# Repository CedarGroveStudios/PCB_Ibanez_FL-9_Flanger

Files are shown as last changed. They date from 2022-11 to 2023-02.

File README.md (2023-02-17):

## PCB_Ibanez_FL-9_Flanger
 An as-built schematic, PCB layout, and service guide to help with the repair of the Ibanez FL-9 Flanger guitar pedal.
 
 [FL9 Flanger Repair Blog (.pdf)](https://github.com/CedarGroveStudios/PCB_Ibanez_FL-9_Flanger/blob/main/docs/repair_blog/Ibanez_FL9_Flanger_Repair_Blog.pdf)

 [New Service Guide (Adafruit Learning System)](https://learn.adafruit.com/u/CGrover/pages/ibanez-fl9-service-guide)

 [New Service Guide (.pdf)](https://github.com/CedarGroveStudios/PCB_Ibanez_FL-9_Flanger/blob/main/docs/new_service_guide/Ibanez_FL9_Service_Guide.pdf)
 
 [KiCAD PCB Design Folder](https://github.com/CedarGroveStudios/PCB_Ibanez_FL-9_Flanger/tree/main/PCB)

 NOTE: The reverse-engineered PCB design was only used for relative component location -- the design is untested.

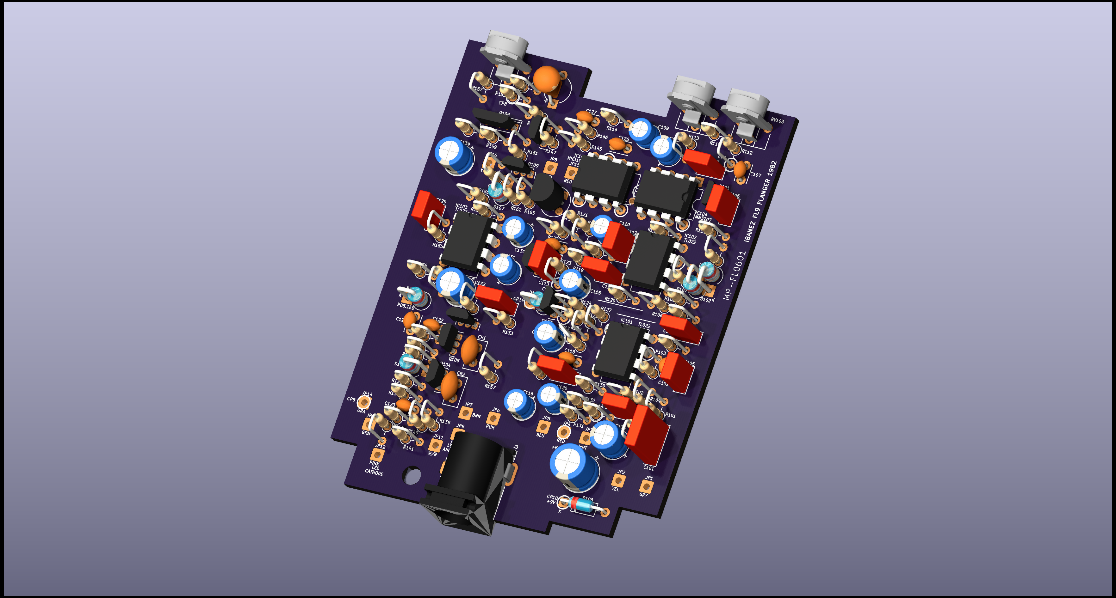
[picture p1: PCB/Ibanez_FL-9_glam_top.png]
PCB 3D rendered view


A thank you to [Mystic Effects Co](https://mysticeffectsco.com) for a helpful and inspiring FL9 capacitor replacement blog post. Also to Panasonic for continuing to maintain on-line datasheets for the bucket-brigade delay and clock driver chip set. Let's not forget how great it is that DigiKey still stocks fresh through-hole capacitors in their produce aisle.

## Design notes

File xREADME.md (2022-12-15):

# PCB_Ibanez_FL-9_Flanger
 An as-built schematic, PCB, and service guide to help with the repair of the Ibanez FL-9 Flanger guitar pedal.
 
 [New Service Guide](https://github.com/CedarGroveStudios/PCB_Ibanez_FL-9_Flanger/blob/main/docs/new_service_guide/Ibanez_FL9_Service_Guide.pdf)
 
 NOTE: At this time, the reverse-engineered PCB design is only useful for relative component location -- the design is non-functional and cannot be fabricated as-is. However, the process to convert a photograph of the traces into a copper layer was tested during this re-engineering project. Further work needs to be done to process the photograph to eliminate shadow and reflective anomolies before a practical test can be conducted. That's on the to-do list.

PCB 3D rendered view

A thank you to [Mystic Effects Co](https://mysticeffectsco.com) for a helpful and inspiring FL9 capacitor replacement blog post. Also to Panasonic for continuing to maintain on-line datasheets for the bucket brigade delay and clock driver chip set. Let's not forget how great it is that @DigiKey still stocks fresh through-hole capacitors in their produce aisle.

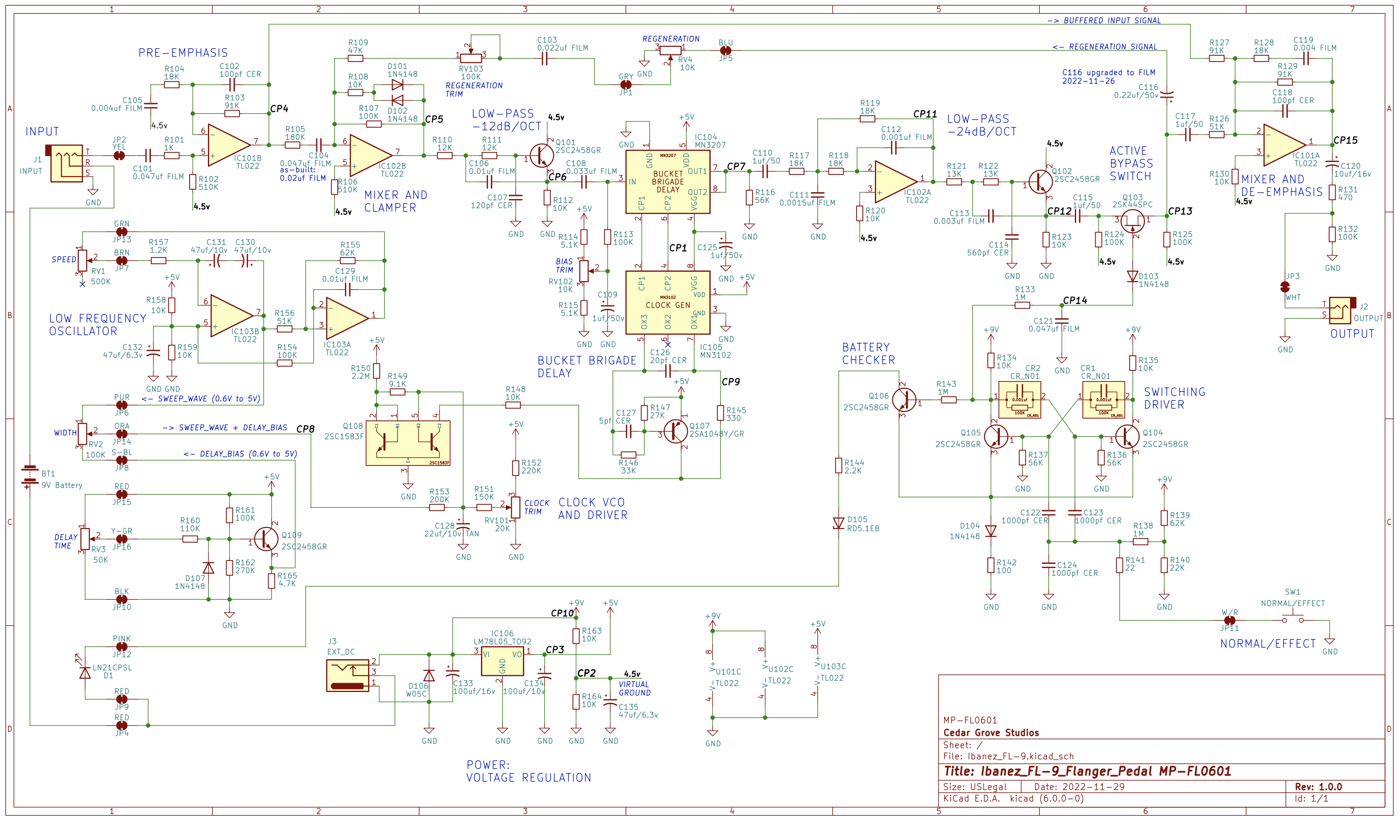
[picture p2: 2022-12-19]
media/guide_photos_and_graphics/schematic.png

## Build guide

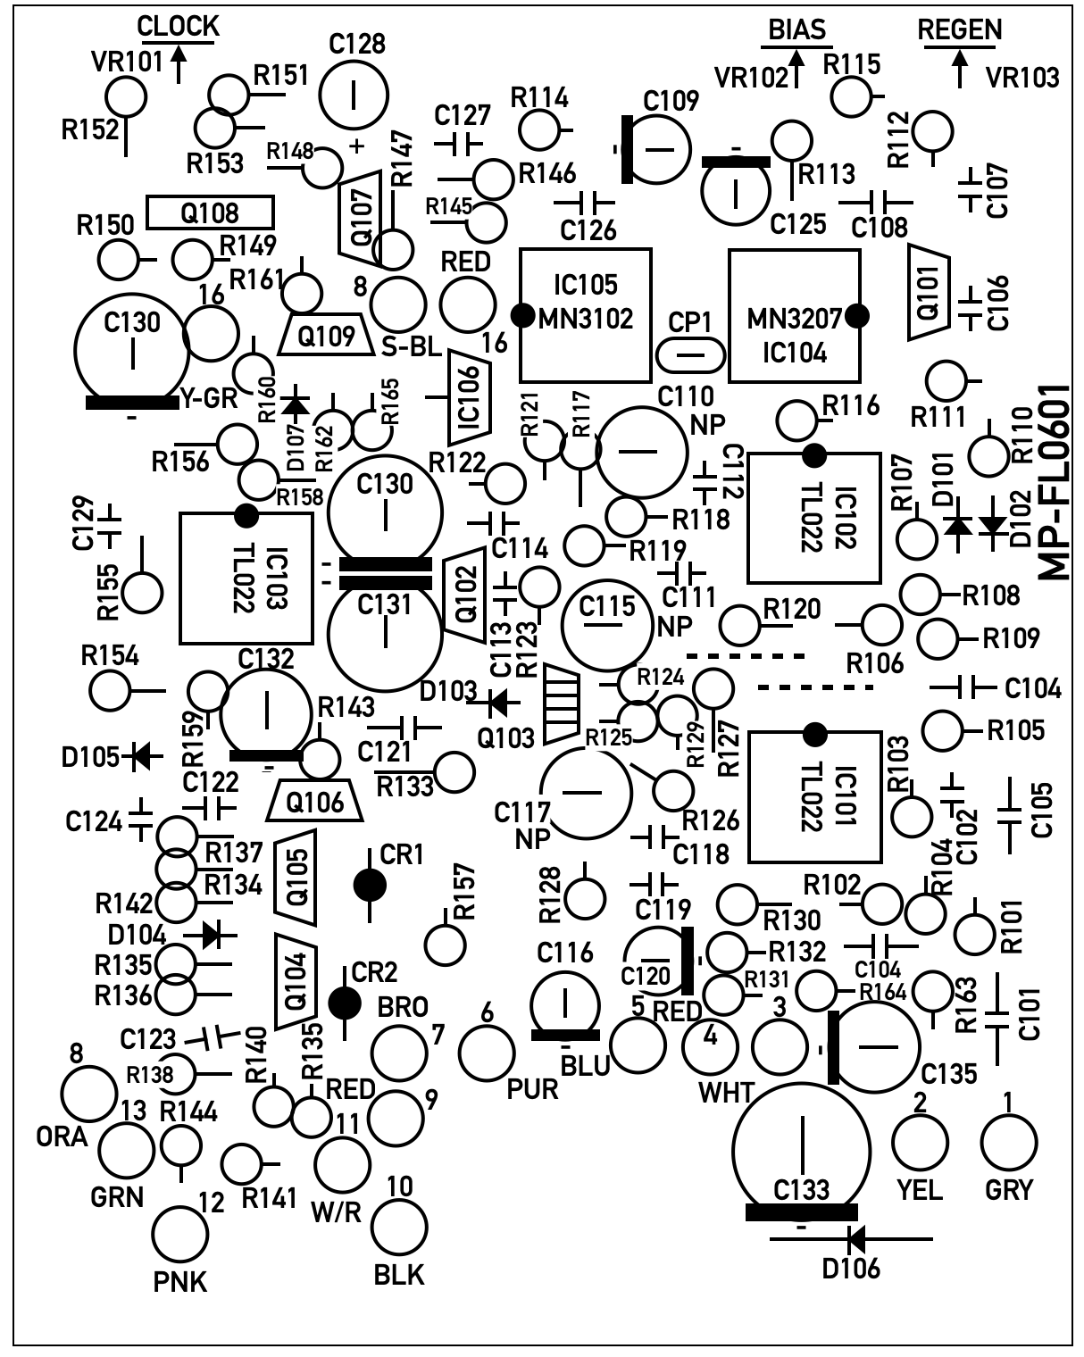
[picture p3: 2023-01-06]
media/guide_photos_and_graphics/new_PCB_TOP_layout.png

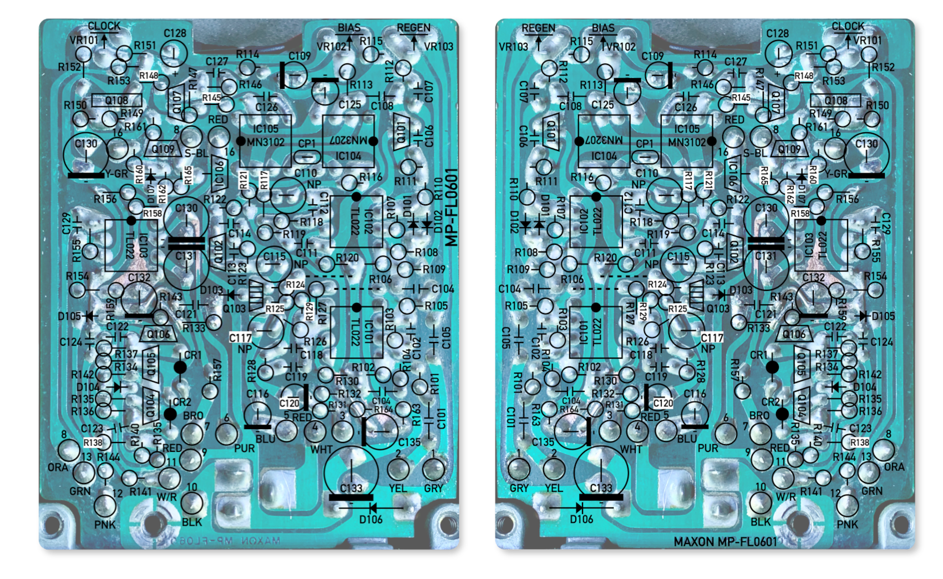
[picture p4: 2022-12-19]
media/guide_photos_and_graphics/PCB_BOT_ortho_render.png

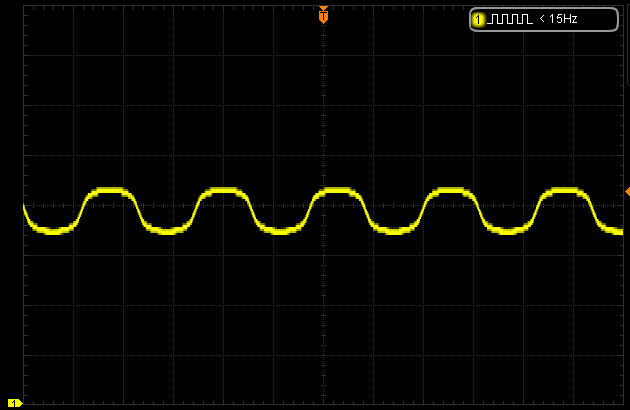
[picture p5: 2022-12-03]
media/guide_testpoint_waveforms/cp6_-12_low-pass.png

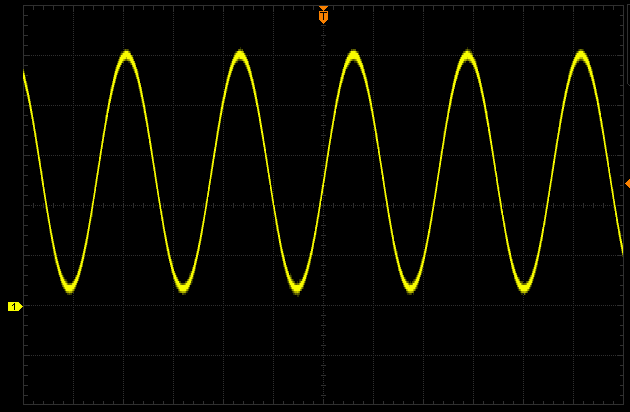
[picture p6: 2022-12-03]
media/guide_testpoint_waveforms/cp0_input_400Hz_2v5.png

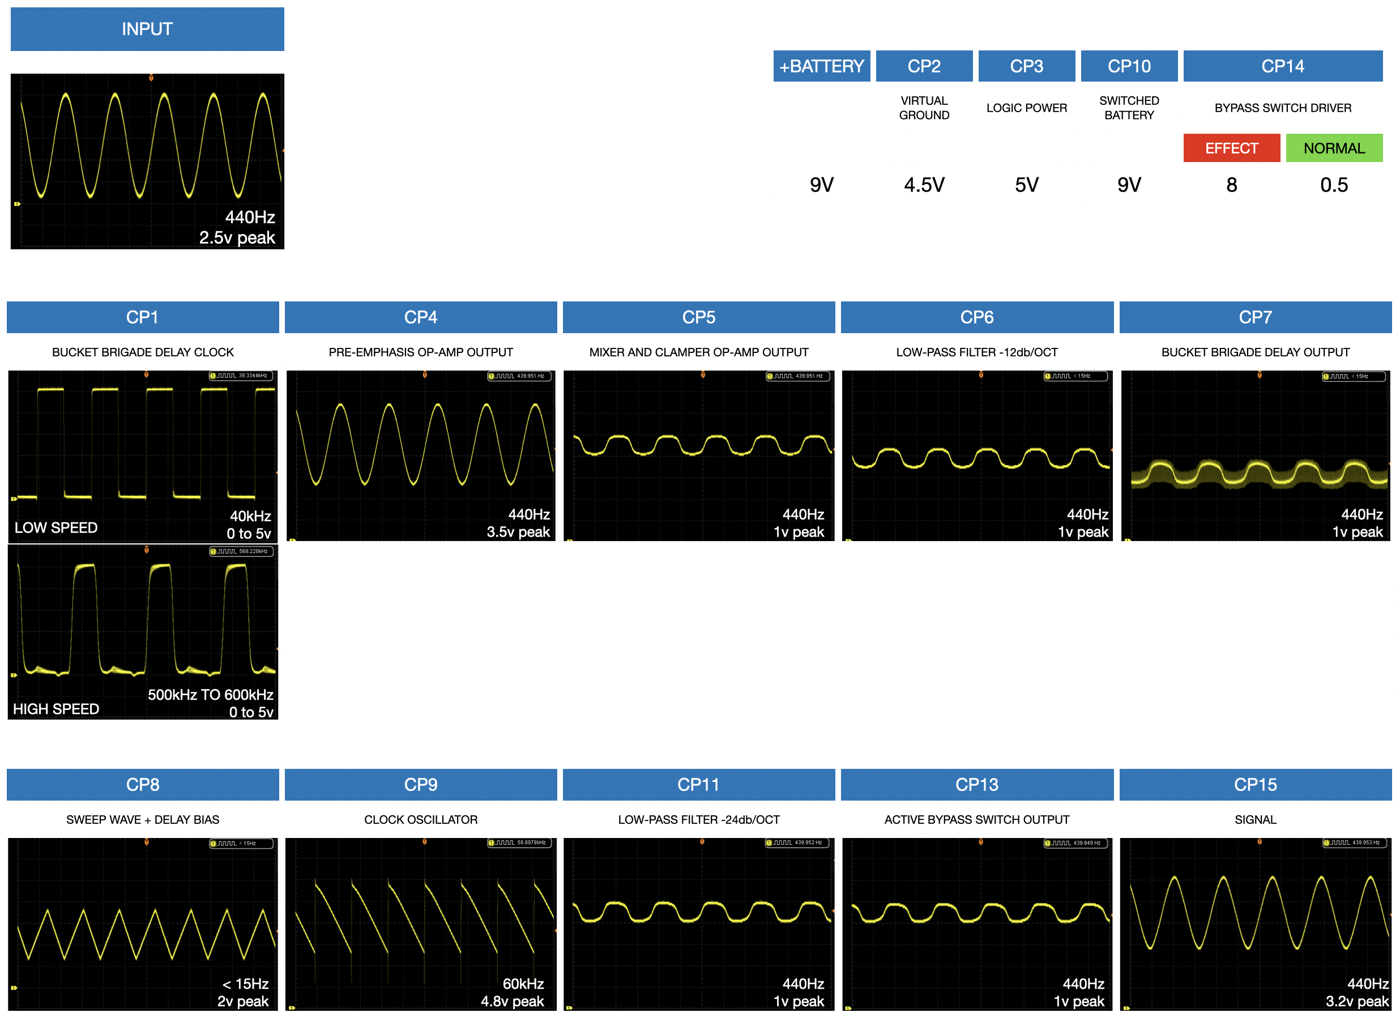
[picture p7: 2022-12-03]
media/guide_photos_and_graphics/cp_waveforms.png

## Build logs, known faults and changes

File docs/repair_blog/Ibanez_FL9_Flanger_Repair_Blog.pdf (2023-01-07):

# Ibanez FL9 Flanger

# Guitar Pedal Repair

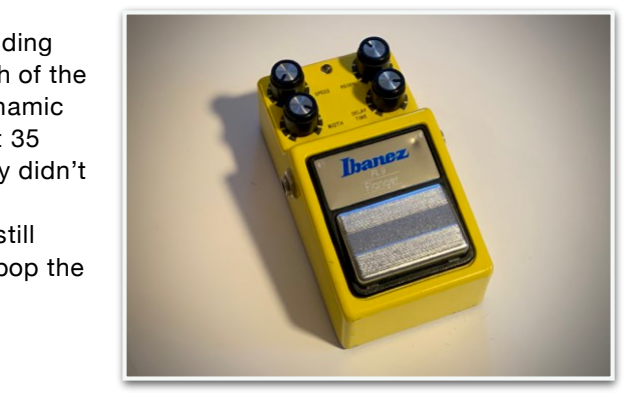
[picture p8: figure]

The flanger effect was sounding

weak. The width and depth of the flange effect wasn’t as dynamic as when the pedal was new just 35 years ago. Replacing the battery didn’t make any difference. Even after cleaning the potentiometers, it still wasn’t working correctly. We’ll pop the covers and take a look.

1 | Ibanez FL9 Guitar Pedal Repair | December 2, 2022

The classic Ibanez FL9 Flanger guitar pedal.

## What’s A Flanger?

Flanging is a time delay effect that originated in recording studios when a track was delayed slightly by touching the outer edge of a tape recorder reel with a finger. Mixed with the source input signal (the “dry” signal), the effect caused a filtering effect that caused different frequency bands to be enhanced or quieted slightly. When the signal delay was varied (swept), the peaks and valleys of the filtering simulated a “whoosh” effect.

The Ibanez FL9 pedal (made in Japan by Maxon) is a hybrid analog/digital delay design that uses a “bucket brigade” integrated circuit to sample slices of the input signal then slightly delays the output of the slices. The overall time delay as well as sweep depth and width are adjustable. The feedback control helps to enhance the effect by adding a portion of the effect signal back into the input of the delay.

Here’s what was found. Patches of the underside of the PCB were corroded. Apparently after decades of use, a few of the aluminum electrolytic capacitors leaked some of their semi-liquid dielectric fluid which quickly attacked the solder joints and copper traces. In one case, the fluid ate away all of the solder for one component, disconnecting from the circuitry.

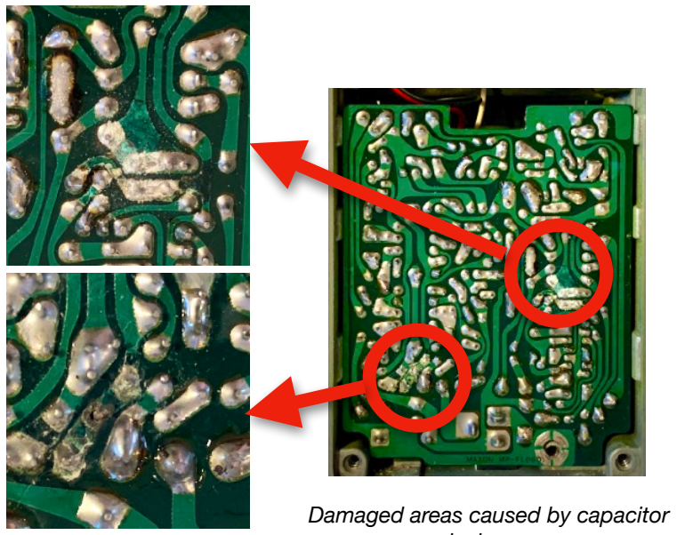
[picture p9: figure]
Damaged areas caused by capacitor

It’s expected that after decades of use, some electronic components would begin to age. The first to go are usually aluminum electrolytic capacitors. And to be safe, all of the aluminum electrolytic capacitors will be replaced — not just the damaged ones — to prevent future capacitor leakage. Hopefully for at least another 30 years.

The first step in repairing the PCB is to remove the damaged capacitors and as much of the corrosion as possible. After cleaning, the surrounding PCB traces will be tested for continuity

## Remove Damaged Capacitors and Clean the PCB

Examination of the board revealed that capacitors C130, C131, C132, C133, and C135 had caused the damage so they were removed first to permit cleaning and examination of the circuit traces. In this case the primary solder removal tool was a professional solder sucker for component leads. A flux-impregnated copper braid was very helpful for removing excess solder from larger areas.

The component side of the PCB was inspected to check for damage of surrounding components. No damage to the top side of the PCB was found.

Next, the damaged areas were thoroughly cleaned with isopropyl alcohol to remove the corrosion and any ancient solder paste.. Finally, stainless steel probes and 400 grit

leakage.

emory cloth were used to remove any remaining oxidation. This is a critical step in the process that requires a very light touch. Let the probes’ weight control the pressure and don’t over do the emory cloth — the copper traces are very thin and can disappear if abraded or picked at too much. It’s nearly impossible to completely recondition the copper circuit traces, so be very careful.

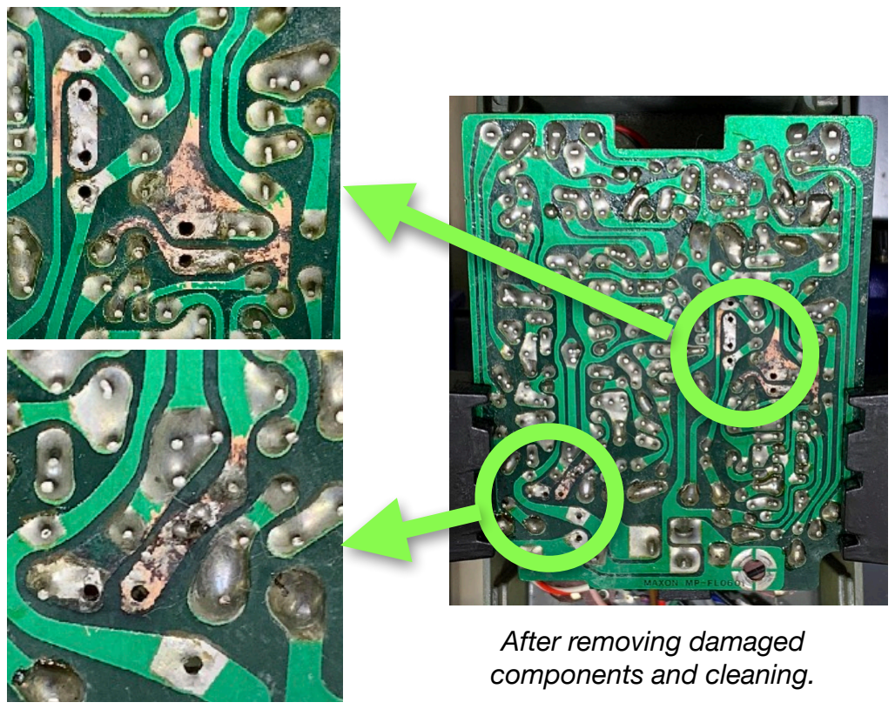
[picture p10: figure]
After removing damaged components and cleaning.

The continuity test revealed five broken copper traces within the damaged areas. We’ll fix those as we replace the surrounding capacitors.

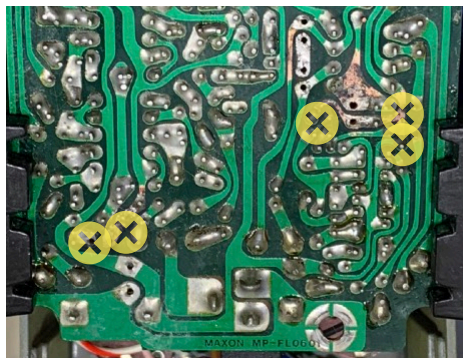
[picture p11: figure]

A list of the remaining electrolytic capacitors was made by examining the schematic. In addition to those already removed, capacitors C109, C116, C120, C125 were targeted for replacement. Three non-polarized aluminum electrolytic capacitors, C110, C115, and C117 were also put on the list for a total of 11 components.

Areas with broken traces.

An order was placed with DigiKey for the replacements including a film capacitor upgrade for C116 and a new film capacitor to replace C121 that was damaged during the removal process. While waiting for the order to be received, a new reverse-engineered schematic and PCB component layout was prepared to help locate the capacitors that needed to be replaced. See the section, Reverse Engineer the PCB for more details.

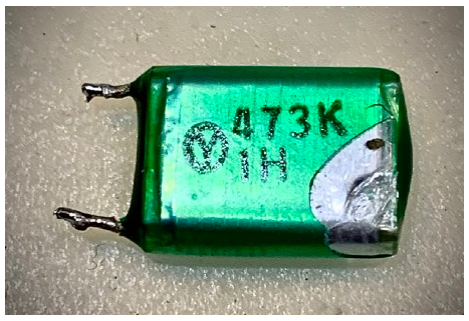
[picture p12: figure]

## Remove and Replace Remaining Capacitors

Once the targeted capacitors were located on the PCB (thanks to the reengineered board layout diagram), each component was removed. The solder sucker tool worked for most and left the traces intact. As each old capacitor is removed, the value and rating were verified with the schematic. When all were removed and new capacitor installation, another inspection of the copper traces was conducted.

Fortunately the component side of the PCB was accurately labeled with each capacitor’s polarity. For the aluminum electrolytic variety, the polarity is marked on the component indicating the negative (-) connection. And to make things easier, the marking on the PCB looked similar to that shown on the component layout legend. The negative wire of the replacement capacitors from DigiKey negative wire was also cut slightly shorter than the positive to aid in identification and insertion into PCB holes.

Handling damage to the
surprisingly fragile coating of C121.

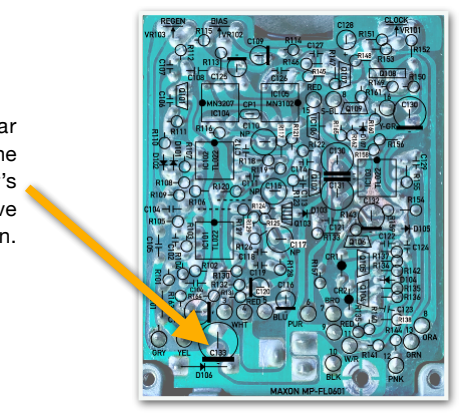
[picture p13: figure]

Component layout legend, bottom view.

The black bar
indicates the
capacitor’s
negative
connection.

Before installing each new capacitor, it was inspected for any signs of distress or leakage. The capacitance value and voltage rating were double-checked and verified with the schematic’s listed component value.

Each a new capacitor was allowed to float very slightly above the circuit board to reduce the stress on the capacitor’s lower seal, hopefully to increase its life span. Once in the holes, the leads were bent slightly to hold the capacitor in position for soldering. Only enough solder was used to cover the open hole and to spread slightly, similar to the factory’s soldering technique.

To minimize value and polarity errors, one capacitor was replaced and soldered at a time. We’ll leave en masse replacements for the more advanced folks who can flawlessly multitask.

For areas with damaged traces that should have been connected to a new capacitor, bent component leads were shaped to follow the damaged track and solder was applied along the length of the wire. This technique is an acceptable way to bridge trace damage and restore continuity. For other damaged tracks, a short leftover component wire was soldered over the break.

Don’t be tempted to apply solder to areas where copper was exposed due to corrosion. It will make repairs more difficult in the future. Instead, we protected the exposed copper traces from oxidation with a conformal coating after the pedal was completely repaired and tested.

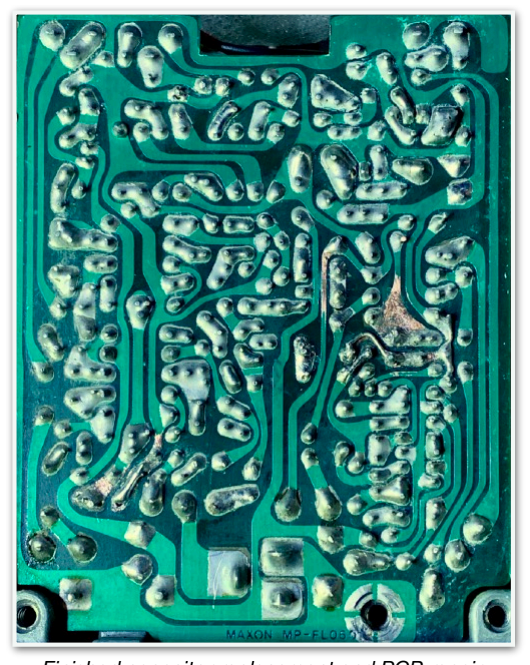
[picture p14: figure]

Finished capacitor replacement and PCB repair before conformal coating application.

One more inspection was conducted after replacing all capacitors and repairing the damaged copper traces. Can’t be too careful when getting ready for applying power to test the reconditioned pedal.

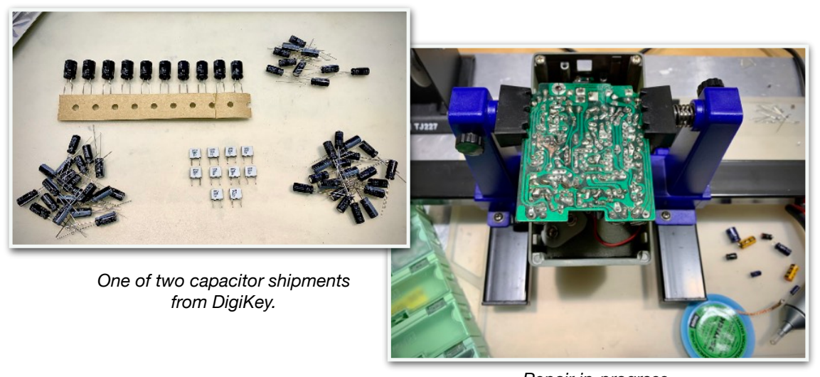
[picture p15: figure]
One of two capacitor shipments from DigiKey.

## Testing and Calibration

When a 9-volt battery was connected, the pedal started working normally. The first check was the red LED. It toggled on and off when the pedal switch was pressed and the voltage on test point CP14 changed appropriately. The static voltage test points +BATTERY, CP2, CP3, and CP10 were checked next. Everything looked nominal. Time for a signal test.

A 2.5-volt peak-to-peak 440Hz sine wave signal was applied to the input jack for further testing and calibration. The output signal was monitored first. It behaved normally in bypass and effects modes and it seemed to change as designed when effect parameters were adjusted. This was a very good sign.

The schematic identifies test points that track the progress of the input signal through stages of the effect as well the calibration of the delay clock and sweep oscillators. All waveforms, clock frequency, and sweep oscillator parameters were nominal and required no adjustments. For a full description of the calibration and adjustment process along with oscilloscope images of the expected waveforms, refer to the new FL9 Service Guide.

The pedal passed all bench tests and was ready for the final test with a guitar input signal. The pedal’s owner, a virtuoso guitar player exclaimed, “The pedal really works great! Brings back memories.” We’ll consider this project completed.

Repair in-progress.

## Reverse Engineer the PCB

The schematic and board layout diagrams in the copy-of-a-copy original service manual were very difficult to discern. In the process of photo-adjusting the old page images, it was decided that starting over with a KiCAD schematic and PCB design would take about the same amount of time and would produce a high quality set of images. So while waiting for the DigiKey capacitor orders to arrive, the reverse-engineering process began.

As with any KiCAD project, it began with the schematic. The layout of the original schematic was preserved as much as possible. Many of the artifacts of the original were corrected and as-built updates to component values were noted.

The most important byproducts of the reverse engineering effort were the component placement layout graphics. This involved a multi-step approach to painstakingly reproduce the original component graphic over a new photograph of the copper traces on the bottom of the PCB. The layout diagrams were pivotal in locating and replacing components as well as finding test points for the final portion of the endeavor.

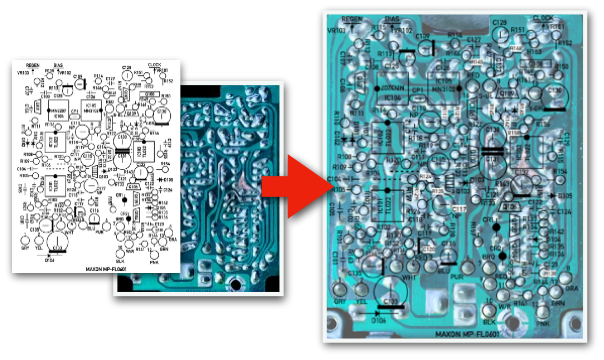
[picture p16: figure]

As it turned out, the original component diagram was true to scale and once overlayed with the KiCAD PCB component layout, it provided the details needed to build a fairly accurate 3D model of the circuit board. That also meant that it would be a relatively simple exercise to add the hand-drawn copper trace layer to the PCB and send it off for manufacturing, should the need ever emerge.

It’s possible to use a PCB photo, convert to a copper layer, and

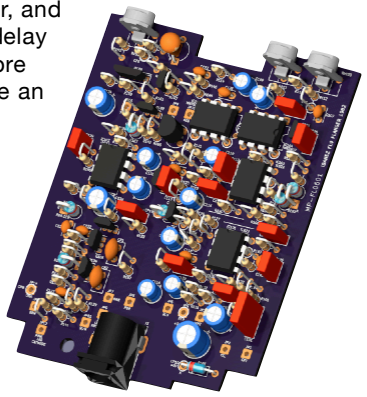
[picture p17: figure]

apply to the KiCAD layout. But since the bucket-brigade delay
integrated circuits are no longer manufactured and therefore difficult to source, manufacturing a new PCB would just be an educational exercise. But an OSH Park After Dark version might make a nice art piece.

From the GitHub repository: KiCAD PCB Design (https://github.com/CedarGroveStudios/PCB_Ibanez_FL-9_Flanger/tree/main/PCB)

## The New Service Guide

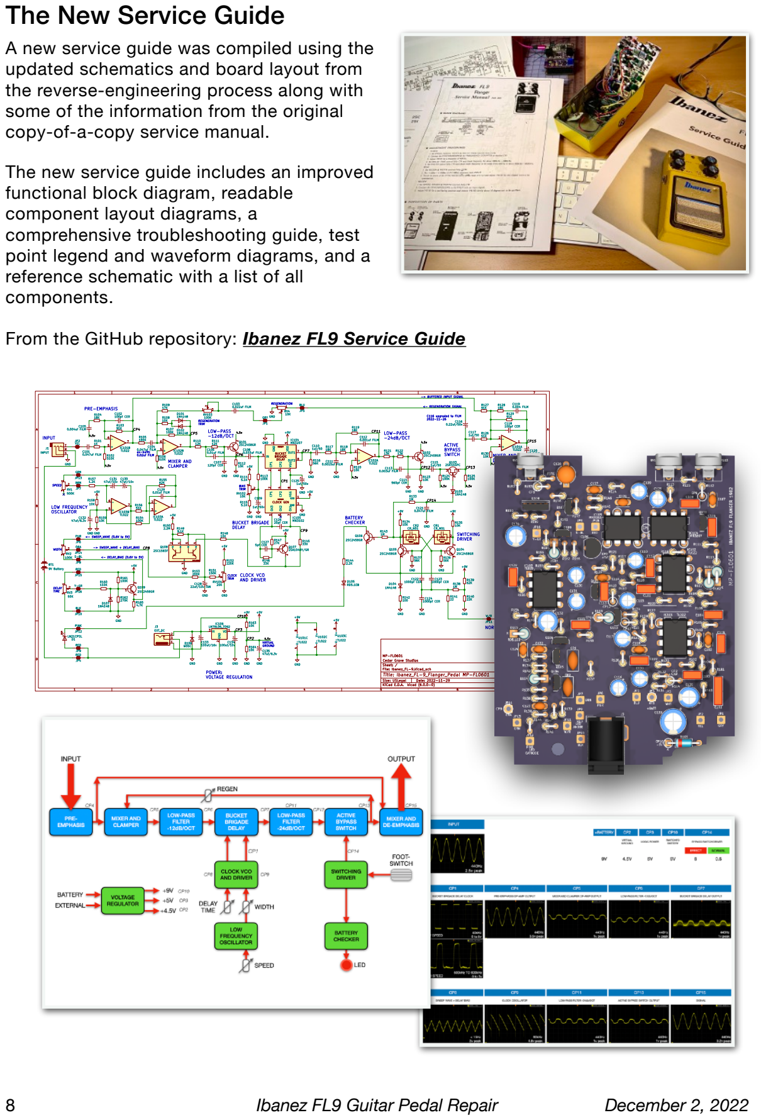
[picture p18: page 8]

A new service guide was compiled using the
updated schematics and board layout from
the reverse-engineering process along with
some of the information from the original
copy-of-a-copy service manual.

The new service guide includes an improved
functional block diagram, readable
component layout diagrams, a
comprehensive troubleshooting guide, test
point legend and waveform diagrams, and a
reference schematic with a list of all
components.

From the GitHub repository: Ibanez FL9 Service Guide (https://github.com/CedarGroveStudios/PCB_Ibanez_FL-9_Flanger/blob/main/docs/new_service_guide/Ibanez_FL9_Service_Guide.pdf)

## Tools and Materials

Silicone Conformal Coating Pen, 5ml:

https://www.digikey.com/en/products/detail/mg-chemicals/422C-P/13277976

Stainless Steel Probe Set, Multiple Tips:

https://www.digikey.com/en/products/detail/ideal-tek-s-a/K6MPTSP/9664592

Solder Wick - 1.5mm x 1.5m:

https://www.adafruit.com/product/149

Solder Wire - 60/40 Rosin Core - 0.5mm, 50 grams:

https://www.adafruit.com/product/1886

Chip Quik Tack Flux 10cc Syringe with Plunger and Tip:

https://www.adafruit.com/product/2667

Digital Genuine Hakko FX-888D Soldering Iron:

https://www.adafruit.com/product/1204

Flush Diagonal Cutters:

https://www.adafruit.com/product/152

Engineer Professional Silicone-Tip Solder Sucker:

https://www.adafruit.com/product/1597

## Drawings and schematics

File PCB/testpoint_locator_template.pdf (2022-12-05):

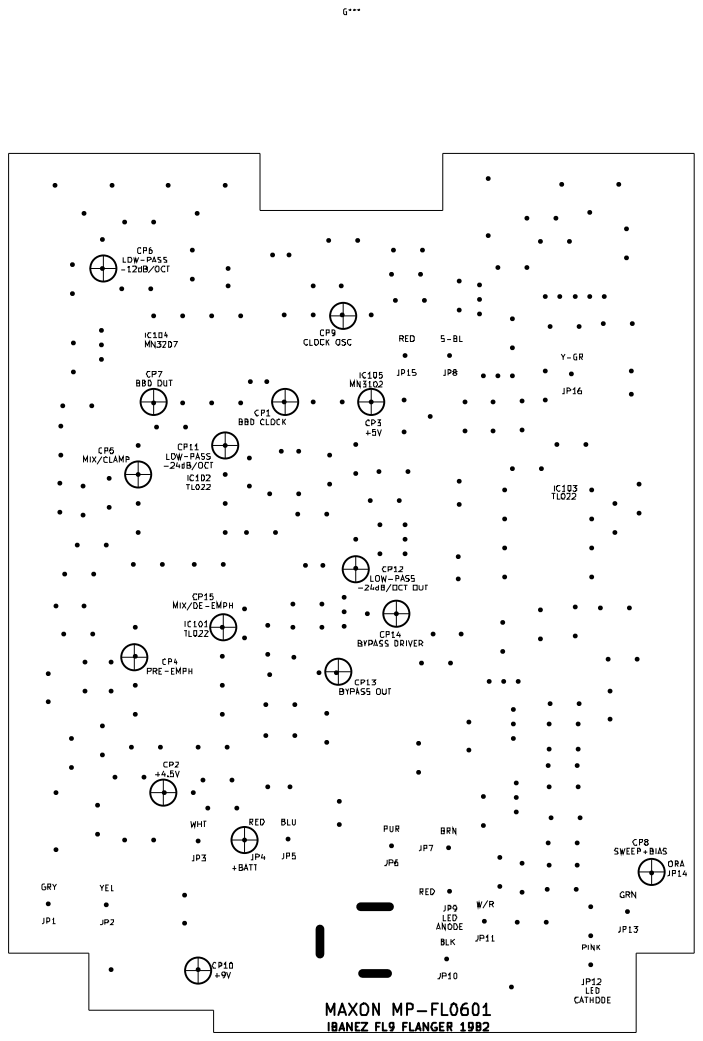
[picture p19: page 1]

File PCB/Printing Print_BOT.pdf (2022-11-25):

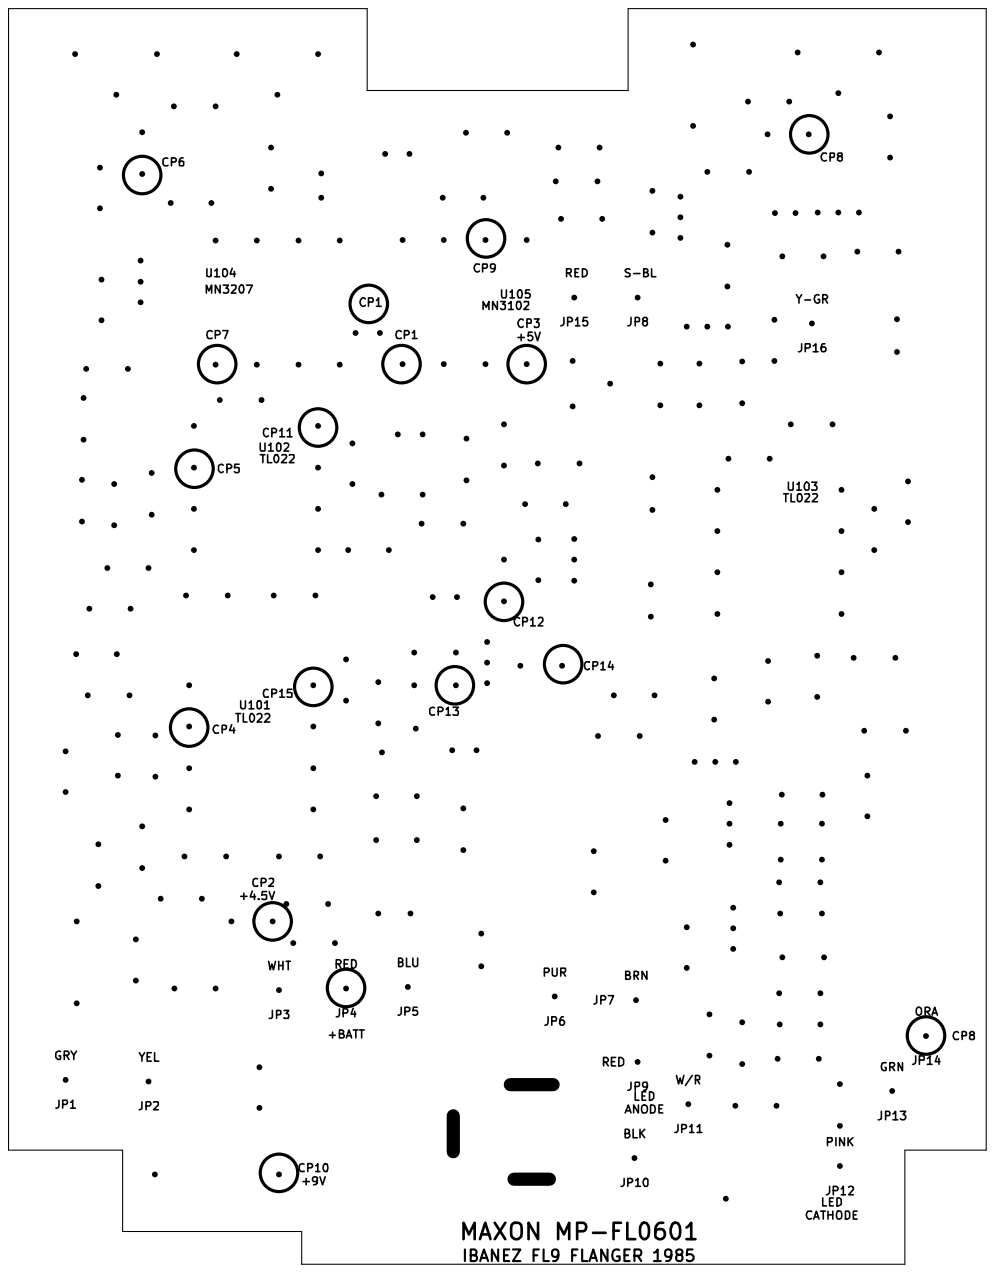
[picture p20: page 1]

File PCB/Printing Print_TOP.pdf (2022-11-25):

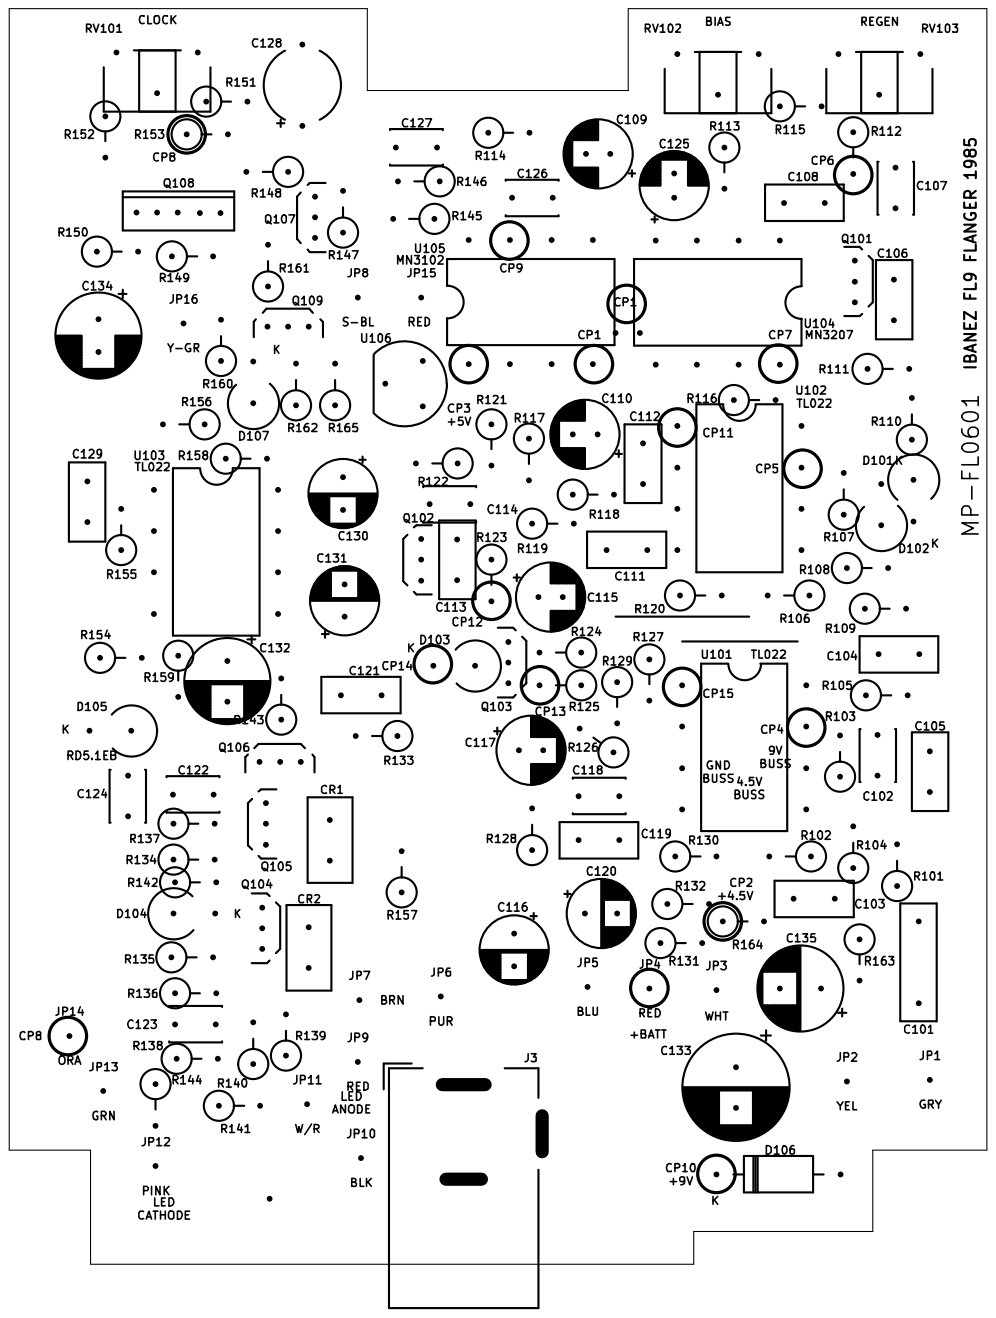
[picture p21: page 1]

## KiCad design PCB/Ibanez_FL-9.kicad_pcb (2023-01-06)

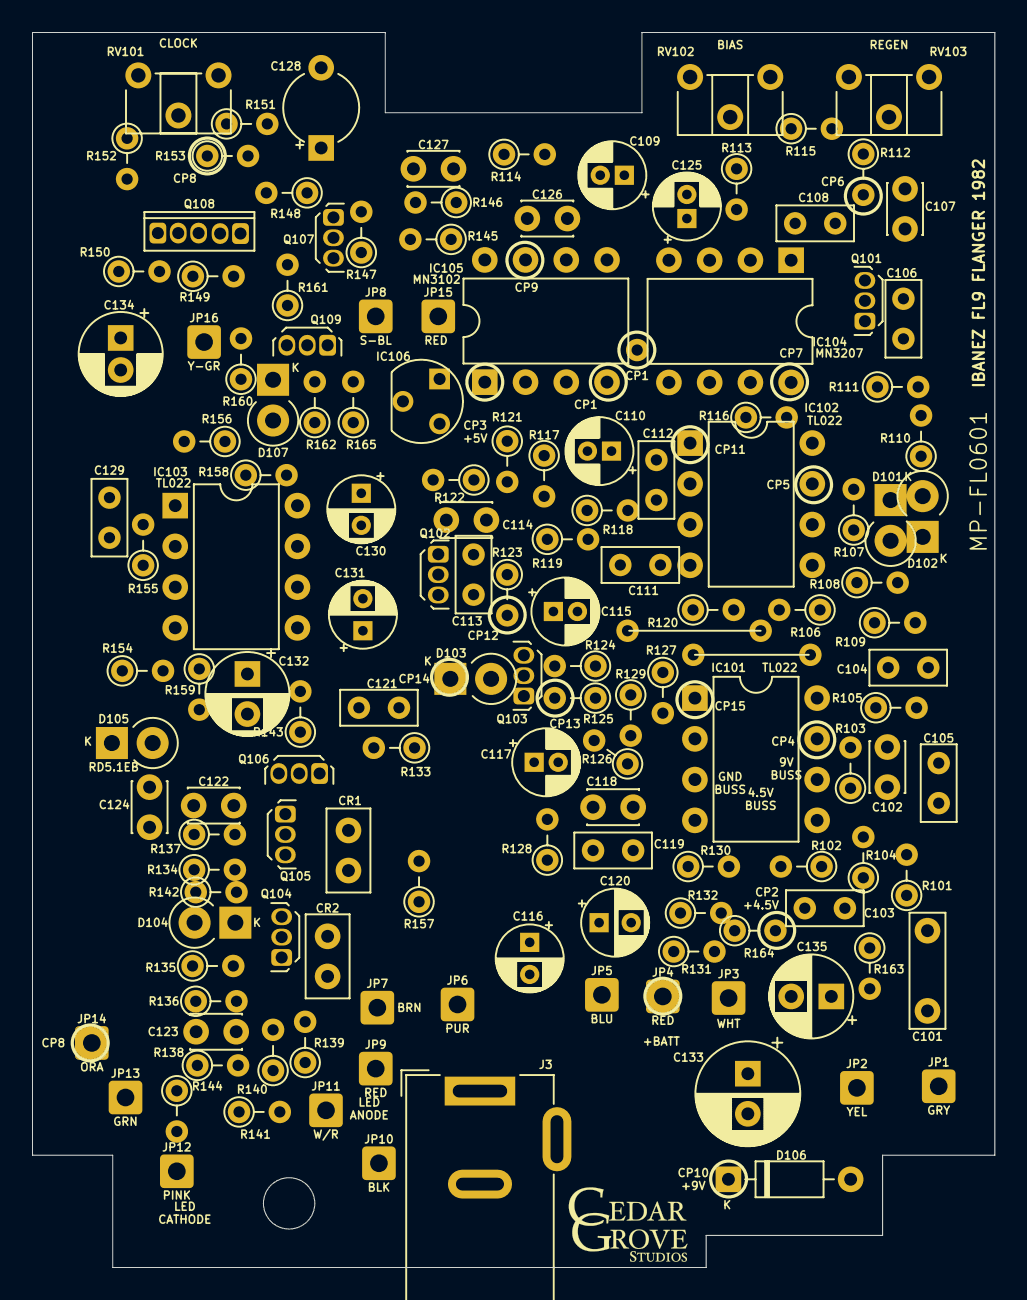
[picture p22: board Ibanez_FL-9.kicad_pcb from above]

Board: 2 copper layers, 60.0 x 77.0 mm, 144 parts (0 on the bottom side), 77 nets, no tracks yet.

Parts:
C101: 0.047uf FILM; C_Rect_L7.0mm_W2.0mm_P5.00mm
C102, C118: 100pf CER; C_Disc_D3.0mm_W2.0mm_P2.50mm
C103: 0.022uf FILM; C_Rect_L4.6mm_W2.0mm_P2.50mm_MKS02_FKP02
C104, C121: 0.047uf FILM; C_Rect_L4.6mm_W2.0mm_P2.50mm_MKS02_FKP02
C105: 0.004uf FILM; C_Rect_L4.6mm_W2.0mm_P2.50mm_MKS02_FKP02
C106, C129: 0.01uf FILM; C_Rect_L4.6mm_W2.0mm_P2.50mm_MKS02_FKP02
C107: 120pf CER; C_Disc_D3.0mm_W2.0mm_P2.50mm
C108: 0.033uf FILM; C_Rect_L4.6mm_W2.0mm_P2.50mm_MKS02_FKP02
C109, C125: 1uf/50v; CP_Radial_D4.0mm_P1.50mm
C110, C115, C117: 1uf/50; CP_Radial_D4.0mm_P1.50mm
C111: 0.0015uf FILM; C_Rect_L4.6mm_W2.0mm_P2.50mm_MKS02_FKP02
C112: 0.001uf FILM; C_Rect_L4.6mm_W2.0mm_P2.50mm_MKS02_FKP02
C113: 0.003uf FILM; C_Rect_L4.6mm_W2.0mm_P2.50mm_MKS02_FKP02
C114: 560pf CER; C_Disc_D3.0mm_W2.0mm_P2.50mm
C116: 0.22uf/50v; CP_Radial_D4.0mm_P2.00mm
C119: 0.004 FILM; C_Rect_L4.6mm_W2.0mm_P2.50mm_MKS02_FKP02
C120: 10uf/16v; CP_Radial_D4.0mm_P2.00mm
C122, C123, C124: 1000pf CER; C_Disc_D3.0mm_W2.0mm_P2.50mm
C126: 20pf CER; C_Disc_D3.0mm_W2.0mm_P2.50mm
C127: 5pf CER; C_Disc_D3.0mm_W2.0mm_P2.50mm
C128: 22uf/10v TAN; CP_Radial_Tantal_D4.5mm_P5.00mm
C130, C131: 47uf/10v; CP_Radial_D4.0mm_P2.00mm
C132, C135: 47uf/6.3v; CP_Radial_D5.0mm_P2.50mm
C133: 100uf/16v; CP_Radial_D6.3mm_P2.50mm
C134: 100uf/10v; CP_Radial_D5.0mm_P2.00mm
CR1, CR2: CR_N01; C_Disc_D5.0mm_W2.5mm_P2.50mm
D101, D102, D103, D104, D107: 1N4148; D_T-1_P2.54mm_Vertical_KathodeUp
D105: RD5.1EB; D_T-1_P2.54mm_Vertical_KathodeUp
D106: W05C; D_DO-35_SOD27_P7.62mm_Horizontal
IC101, IC102, IC103: TL022; DIP-8_W7.62mm
IC104: MN3207; DIP-8_W7.62mm
IC105: MN3102; DIP-8_W7.62mm
IC106: LM78L05_TO92; TO-92
J3: EXT_DC; BarrelJack_Wuerth_6941xx301002
JP1: GRY; SolderWire-0.5sqmm_1x01_D0.9mm_OD2.1mm
JP2: YEL; SolderWire-0.5sqmm_1x01_D0.9mm_OD2.1mm
JP3: WHT; SolderWire-0.5sqmm_1x01_D0.9mm_OD2.1mm
JP4, JP9, JP15: RED; SolderWire-0.5sqmm_1x01_D0.9mm_OD2.1mm
JP5: BLU; SolderWire-0.5sqmm_1x01_D0.9mm_OD2.1mm
JP6: PUR; SolderWire-0.5sqmm_1x01_D0.9mm_OD2.1mm
JP7: BRN; SolderWire-0.5sqmm_1x01_D0.9mm_OD2.1mm
JP8: S-BL; SolderWire-0.5sqmm_1x01_D0.9mm_OD2.1mm
JP10: BLK; SolderWire-0.5sqmm_1x01_D0.9mm_OD2.1mm
JP11: W/R; SolderWire-0.5sqmm_1x01_D0.9mm_OD2.1mm
JP12: PINK; SolderWire-0.5sqmm_1x01_D0.9mm_OD2.1mm
JP13: GRN; SolderWire-0.5sqmm_1x01_D0.9mm_OD2.1mm
JP14: ORA; SolderWire-0.5sqmm_1x01_D0.9mm_OD2.1mm
JP16: Y-GR; SolderWire-0.5sqmm_1x01_D0.9mm_OD2.1mm
Q101, Q102, Q104, Q105, Q106, Q109: 2SC2458GR; TO-92Flat
Q103: 2SK44SPC; TO-92Flat
Q107: 2SA1048Y/GR; TO-92Flat
Q108: 2SC1583F; TO-92Flat_5-PIN
R101: 1K; R_Axial_DIN0204_L3.6mm_D1.6mm_P2.54mm_Vertical
R102, R106: 510K; R_Axial_DIN0204_L3.6mm_D1.6mm_P2.54mm_Vertical
R103, R127, R129: 91K; R_Axial_DIN0204_L3.6mm_D1.6mm_P2.54mm_Vertical
R104, R117, R118, R119, R128: 18K; R_Axial_DIN0204_L3.6mm_D1.6mm_P2.54mm_Vertical
R105: 180K; R_Axial_DIN0204_L3.6mm_D1.6mm_P2.54mm_Vertical
R107, R113, R124, R125, R132, R154, R161: 100K; R_Axial_DIN0204_L3.6mm_D1.6mm_P2.54mm_Vertical
R108, R112, R120, R123, R130, R134, R135, R148, R158, R159, R163, R164: 10K; R_Axial_DIN0204_L3.6mm_D1.6mm_P2.54mm_Vertical
R109: 47K; R_Axial_DIN0204_L3.6mm_D1.6mm_P2.54mm_Vertical
R110, R111: 12K; R_Axial_DIN0204_L3.6mm_D1.6mm_P2.54mm_Vertical
R114, R115: 5.1K; R_Axial_DIN0204_L3.6mm_D1.6mm_P2.54mm_Vertical
R116, R136, R137: 56K; R_Axial_DIN0204_L3.6mm_D1.6mm_P2.54mm_Vertical
R121, R122: 13K; R_Axial_DIN0204_L3.6mm_D1.6mm_P2.54mm_Vertical
R126, R156: 51K; R_Axial_DIN0204_L3.6mm_D1.6mm_P2.54mm_Vertical
R131: 470; R_Axial_DIN0204_L3.6mm_D1.6mm_P2.54mm_Vertical
R133, R138, R143: 1M; R_Axial_DIN0204_L3.6mm_D1.6mm_P2.54mm_Vertical
R139, R155: 62K; R_Axial_DIN0204_L3.6mm_D1.6mm_P2.54mm_Vertical
R140: 22K; R_Axial_DIN0204_L3.6mm_D1.6mm_P2.54mm_Vertical
R141: 22; R_Axial_DIN0204_L3.6mm_D1.6mm_P2.54mm_Vertical
R142: 100; R_Axial_DIN0204_L3.6mm_D1.6mm_P2.54mm_Vertical
R144: 2.2K; R_Axial_DIN0204_L3.6mm_D1.6mm_P2.54mm_Vertical
R145: 330; R_Axial_DIN0204_L3.6mm_D1.6mm_P2.54mm_Vertical
R146: 33K; R_Axial_DIN0204_L3.6mm_D1.6mm_P2.54mm_Vertical
R147: 27K; R_Axial_DIN0204_L3.6mm_D1.6mm_P2.54mm_Vertical
R149: 9.1K; R_Axial_DIN0204_L3.6mm_D1.6mm_P2.54mm_Vertical
R150: 2.2M; R_Axial_DIN0204_L3.6mm_D1.6mm_P2.54mm_Vertical
R151: 150K; R_Axial_DIN0204_L3.6mm_D1.6mm_P2.54mm_Vertical
R152: 220K; R_Axial_DIN0204_L3.6mm_D1.6mm_P2.54mm_Vertical
R153: 200K; R_Axial_DIN0204_L3.6mm_D1.6mm_P2.54mm_Vertical
R157: 1.2K; R_Axial_DIN0204_L3.6mm_D1.6mm_P2.54mm_Vertical
R160: 110K; R_Axial_DIN0204_L3.6mm_D1.6mm_P2.54mm_Vertical
R162: 270K; R_Axial_DIN0204_L3.6mm_D1.6mm_P2.54mm_Vertical
R165: 4.7K; R_Axial_DIN0204_L3.6mm_D1.6mm_P2.54mm_Vertical
RV101: 20K; Potentiometer_ACP_CA6-H2,5_Horizontal
RV102: 10K; Potentiometer_ACP_CA6-H2,5_Horizontal
RV103: 100K; Potentiometer_ACP_CA6-H2,5_Horizontal

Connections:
+5V: C134.1, IC103.8 (V+), IC104.5 (VDD), IC105.1 (VDD), IC106.1 (VO), Q107.1 (E), Q109.2 (C), R114.1, R147.1, R150.2, R152.2, R158.2, R161.2
+9V: C133.1, D106.1 (K), IC101.8 (V+), IC102.8 (V+), IC106.3 (VI), J3.2, R134.1, R135.1, R139.2, R163.1
/4.5v: C105.1, C135.1, Q101.2 (C), Q102.2 (C), R102.2, R106.2, R120.2, R124.1, R125.1, R130.2, R163.2, R164.2
/CP1: IC104.6 (CP2), IC105.4 (CP2)
/CP4: C102.2, IC101.7, R103.2, R105.1, R127.1
/CP5: D101.1 (K), D102.2 (A), IC102.7, R107.2, R110.1
/CP6: C106.2, C108.1, Q101.3 (E), R112.2
/CP7: C110.1, IC104.7 (OUT1), IC104.8 (OUT2), R116.1
/CP9: C126.2, IC105.7 (OX1), R145.1
/CP11: C112.2, IC102.1, R119.1, R121.2
/CP12: C113.2, C115.1, Q102.3 (E), R123.2
/CP13: C116.1, C117.1, Q103.1 (S), R125.2
/CP14: C121.2, D103.1 (K), R133.1
/CP15: C118.2, C119.2, C120.1, IC101.1, R129.2
GND: C107.1, C109.2, C111.1, C114.1, C121.1, C124.1, C125.2, C128.2, C132.2, C133.2, C134.2, C135.2, D106.2 (A), D107.2 (A), IC101.4 (V-), IC102.4 (V-), IC103.4 (V-), IC104.1 (GND), IC105.3 (GND), IC106.2 (GND), J3.1, Q108.3 (E), R112.1, R115.2, R116.2, R123.1, R132.1, R136.1, R137.1, R140.2, R142.1, R159.2, R162.1, R164.1, R165.1, RV101.1
unnamed: C101.2, R101.1
unnamed: C102.1, IC101.6 (-), R103.1, R104.2
unnamed: C103.1, RV103.2, RV103.3
unnamed: C104.1, R105.2
unnamed: C104.2, IC102.6 (-), R107.1, R108.1, R109.1
unnamed: C105.2, R104.1
unnamed: C106.1, R110.2, R111.2
unnamed: C107.2, Q101.1 (B), R111.1
unnamed: C108.2, IC104.3 (IN), R113.2
unnamed: C109.1, R113.1, RV102.2
unnamed: C110.2, R117.1
unnamed: C111.2, R117.2, R118.1, R119.2
unnamed: C112.1, IC102.2 (-), R118.2
unnamed: C113.1, R121.1, R122.1
unnamed: C114.2, Q102.1 (B), R122.2
unnamed: C115.2, Q103.3 (D), R124.2
unnamed: C116.2, JP5.1 (A)
unnamed: C117.2, R126.2
unnamed: C118.1, IC101.2 (-), R126.1, R127.2, R128.2, R129.1
unnamed: C119.1, R128.1
unnamed: C120.2, R131.1
unnamed: C122.1, C123.1, C124.2, R138.2, R141.1
unnamed: C122.2, CR1.1, Q105.1 (B), R137.2
unnamed: C123.2, CR2.2, Q104.1 (B), R136.2
unnamed: C125.1, IC104.4 (VGG), IC105.8 (VGG)
unnamed: C126.1, C127.1, IC105.5 (OX3), R146.1
unnamed: C127.2, Q107.3 (B), R146.2, R147.2
unnamed: C128.1, Q108.5 (B2), R149.2, R151.2, R153.2
unnamed: C129.1, IC103.2 (-), R154.1
unnamed: C129.2, IC103.1, R155.2
unnamed: C130.1, IC103.7, R156.1
unnamed: C130.2, C131.2
unnamed: C131.1, IC103.6 (-), R157.1
unnamed: C132.1, IC103.5 (+), R154.2, R158.1, R159.1
unnamed: CR1.2, Q104.2 (C), R135.2
unnamed: CR2.1, Q105.2 (C), R133.2, R134.2, R143.2
unnamed: D101.2 (A), D102.1 (K), R108.2
unnamed: D103.2 (A), Q103.2 (G)
unnamed: D104.1 (K), R142.2
unnamed: D104.2 (A), Q104.3 (E), Q105.3 (E), Q106.3 (E)
unnamed: D105.2 (A), R144.1
unnamed: D107.1 (K), Q109.1 (B), R160.1, R161.1, R162.2
unnamed: IC101.3 (+), R130.1
unnamed: IC101.5 (+), R101.2, R102.1
unnamed: IC102.3 (+), R120.1
unnamed: IC102.5 (+), R106.1
unnamed: IC103.3 (+), R155.1, R156.2
unnamed: IC104.2 (CP1), IC105.2 (CP1)
unnamed: JP3.1 (A), R131.2, R132.2
unnamed: Q109.3 (E), R165.2
unnamed: JP11.1 (A), R141.2
unnamed: Q106.1 (B), R143.1
unnamed: Q106.2 (C), R144.2
unnamed: Q107.2 (C), R145.2, R148.1
unnamed: Q108.1 (B1), Q108.2 (C1), R149.1, R150.1
unnamed: Q108.4 (C2), R148.2
unnamed: R109.2, RV103.1
unnamed: R114.2, RV102.1
unnamed: R115.1, RV102.3
unnamed: R138.1, R139.1, R140.1
unnamed: R151.1, RV101.2
unnamed: R152.1, RV101.3

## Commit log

2022-11-21 initial repo load
    [Ibanez_FL-9.kicad_pcb, Ibanez_FL-9.kicad_sch, Ibanez_FL-9.sch]
2022-11-21 update docs
    [Ibanez_FL-9.kicad_sch]
2022-11-21 update docs; add BOM
    [Ibanez_FL-9.csv, Ibanez_FL-9.kicad_sch]
2022-11-21 update docs; correct component labels and footprints
    [Ibanez_FL-9.kicad_pcb, Ibanez_FL-9.kicad_sch]
2022-11-22 update pcb layout
    [Ibanez_FL-9.kicad_pcb]
2022-11-23 update pcb design
    [Ibanez_FL-9.kicad_pcb]
2022-11-23 pcb layout v1.0
    [Ibanez_FL-9.kicad_pcb, Ibanez_FL-9.kicad_sch]
2022-11-23 add pcb 3d renders
2022-11-23 add custom components; fix all labels
    [Ibanez_FL-9.kicad_pcb, Ibanez_FL-9.kicad_sch]
2022-11-23 update test points; add hybrid devices
    [Ibanez_FL-9.kicad_pcb, Ibanez_FL-9.kicad_sch]
2022-11-25 update board layout and docs
    [Ibanez_FL-9-B_Cu.gbr, Ibanez_FL-9-B_Mask.gbr, Ibanez_FL-9-B_Silkscreen.gbr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]
2022-11-27 update schematic, guide, and docs
    [Ibanez_FL-9-B_Cu.gbr, Ibanez_FL-9-B_Mask.gbr, Ibanez_FL-9-B_Silkscreen.gbr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]
2022-11-28 update original pcb date
    [Ibanez_FL-9.kicad_pcb]
2022-11-30 update PCB and docs
    [Ibanez_FL-9-B_Cu.gbr, Ibanez_FL-9-B_Mask.gbr, Ibanez_FL-9-B_Silkscreen.gbr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]
2022-12-03 update docs; add PCB design warning
2022-12-03 update docs; add reverse-engineered PCB functionality warning
2022-12-04 update testpoints on bot silk; fix spelling
    [Ibanez_FL-9.kicad_pcb, Ibanez_FL-9.kicad_sch]
2022-12-21 update trace enhanced photo
2023-01-06 begin process to add hand-drawn traces
2023-01-06 add clean bottom traces image
2023-01-06 update jumper and CP1
    [Ibanez_FL-9.kicad_pcb]
2023-01-06 add hand-drawn PCB
    [Ibanez_FL-9-B_Cu.gbr, Ibanez_FL-9-B_Mask.gbr, Ibanez_FL-9-B_Silkscreen.gbr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]
2023-01-07 update hand-drawn PCB design
2023-01-07 add hand-drawn PCB design
    [Ibanez_FL-9-B_Cu.gbr, Ibanez_FL-9-B_Mask.gbr, Ibanez_FL-9-B_Silkscreen.gbr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]
2023-01-07 move hand-drawn PCB design to private repo
    [Ibanez_FL-9-B_Cu.gbr, Ibanez_FL-9-B_Mask.gbr, Ibanez_FL-9-B_Silkscreen.gbr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]
